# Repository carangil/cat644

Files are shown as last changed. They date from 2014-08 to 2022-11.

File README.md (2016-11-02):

cat644
======

Cat-644 is a microcomputer based around the Atmega644 microcontroller.  This repository will hold both hardware designs and software source code.

dirs:

schematics/  	hardware information
cat1/  			OLD hardware test routines.  Will be deleted when CAT-OS is finished
cat-os/			'scratchpad' OS.  Being built out of code in the cat1 directory

LICENSE

All code is under GPL v2.  See LICENSE file for details.

All code written by Mark Sherman, with a few exceptions:

'wait until' function taken from arduino-tvout: http://code.google.com/p/arduino-tvout/  (License: MIT License)

The 'general idea' of VGA generation from an AVR was taken from these resources:
http://www.lucidscience.com/pro-vga%20video%20generator-1.aspx
http://quinndunki.com/blondihacks/?p=955
http://avga.prometheus4.com/

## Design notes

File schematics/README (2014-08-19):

.sch and .sym files are in gEDA format.
The 'schematics' folder must be added to your gEDA configuration as a library.

'fullcomputer.sch' contains the entire design, and is provided in both eps and png formats.

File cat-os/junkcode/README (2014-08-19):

Code here is not integrated into the cat-os project currently, but is kept here as a backup.  Eventually the junkcode folder will be empty, and the project will be done!

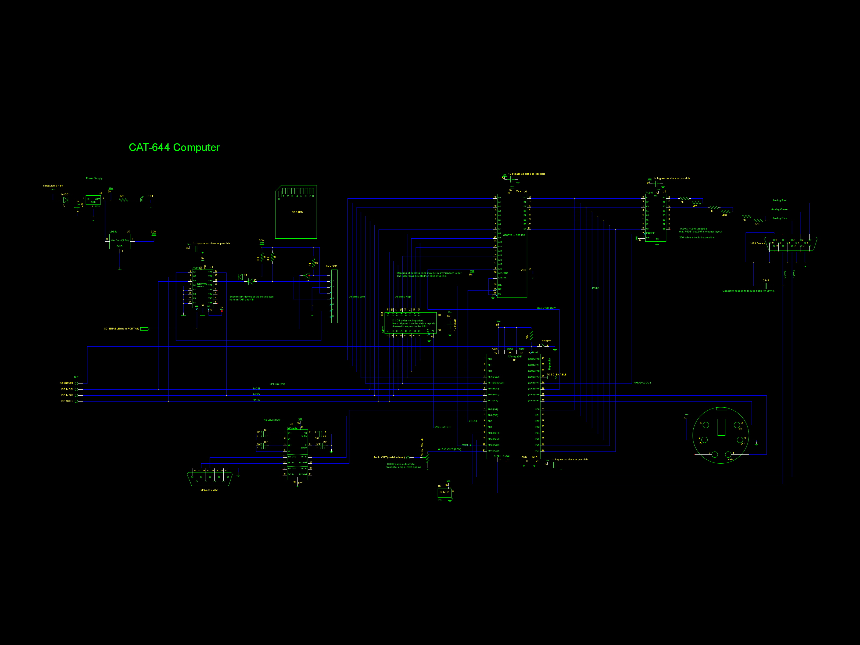
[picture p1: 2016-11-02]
schematics/fullcomputer.png

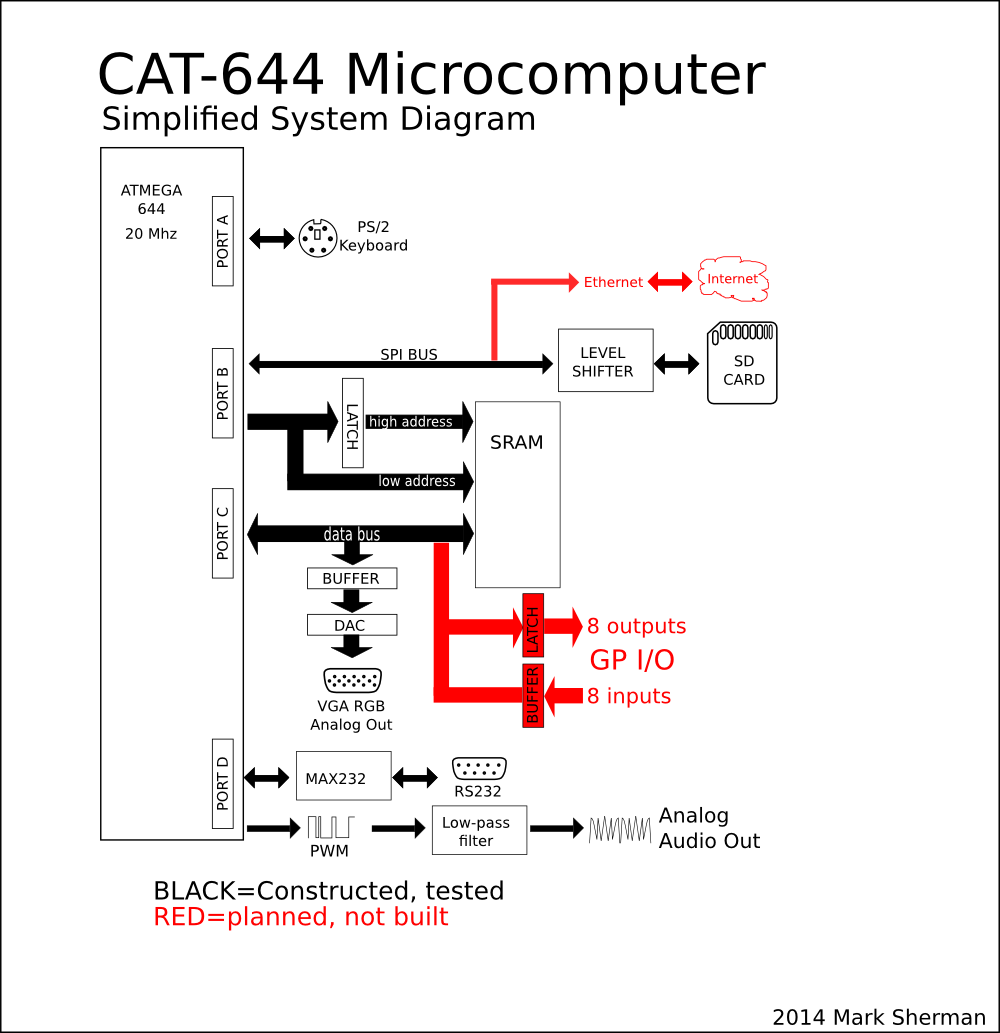
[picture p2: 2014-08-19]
schematics/sysdiag.png

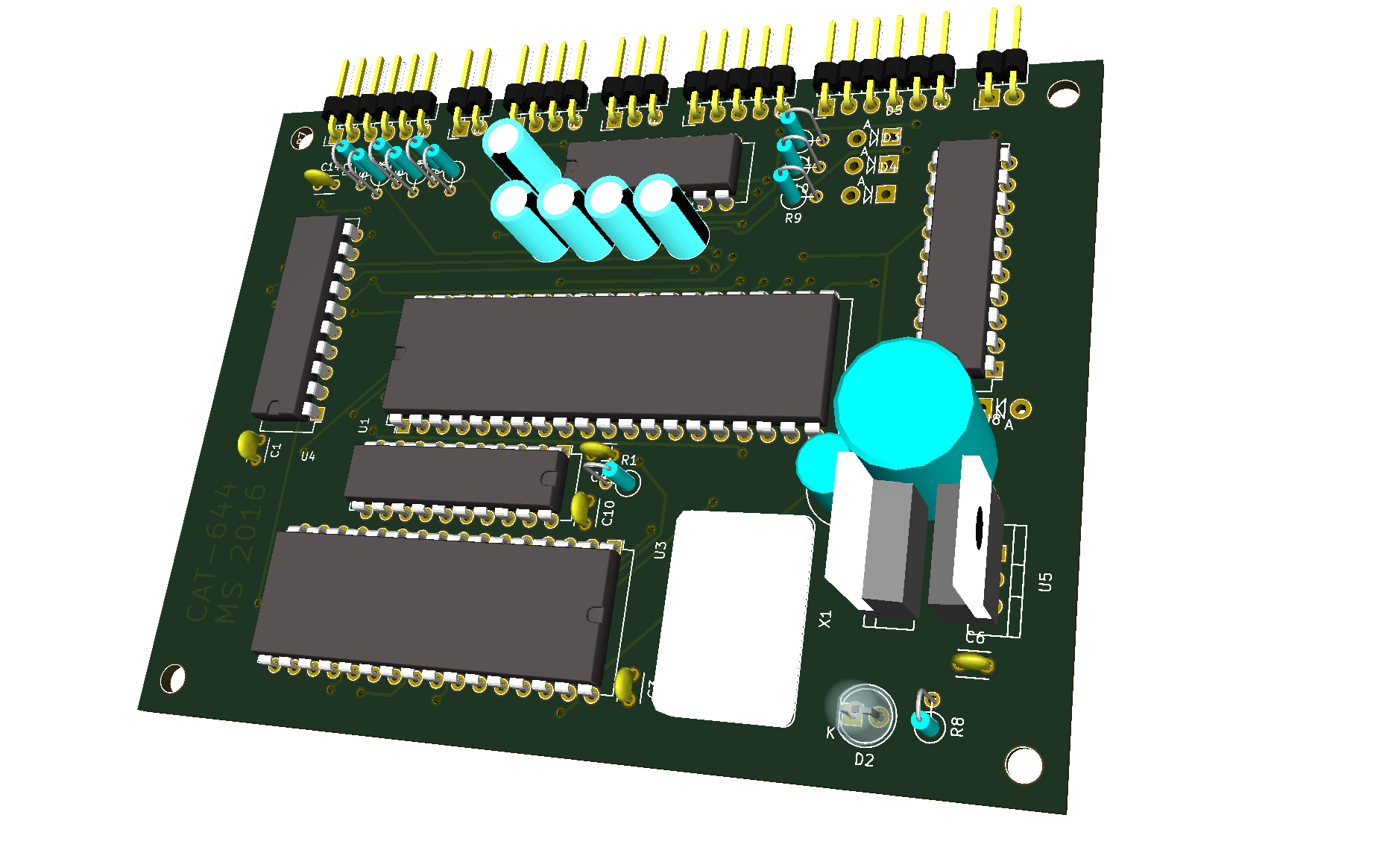
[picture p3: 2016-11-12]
kicad/cat644.png

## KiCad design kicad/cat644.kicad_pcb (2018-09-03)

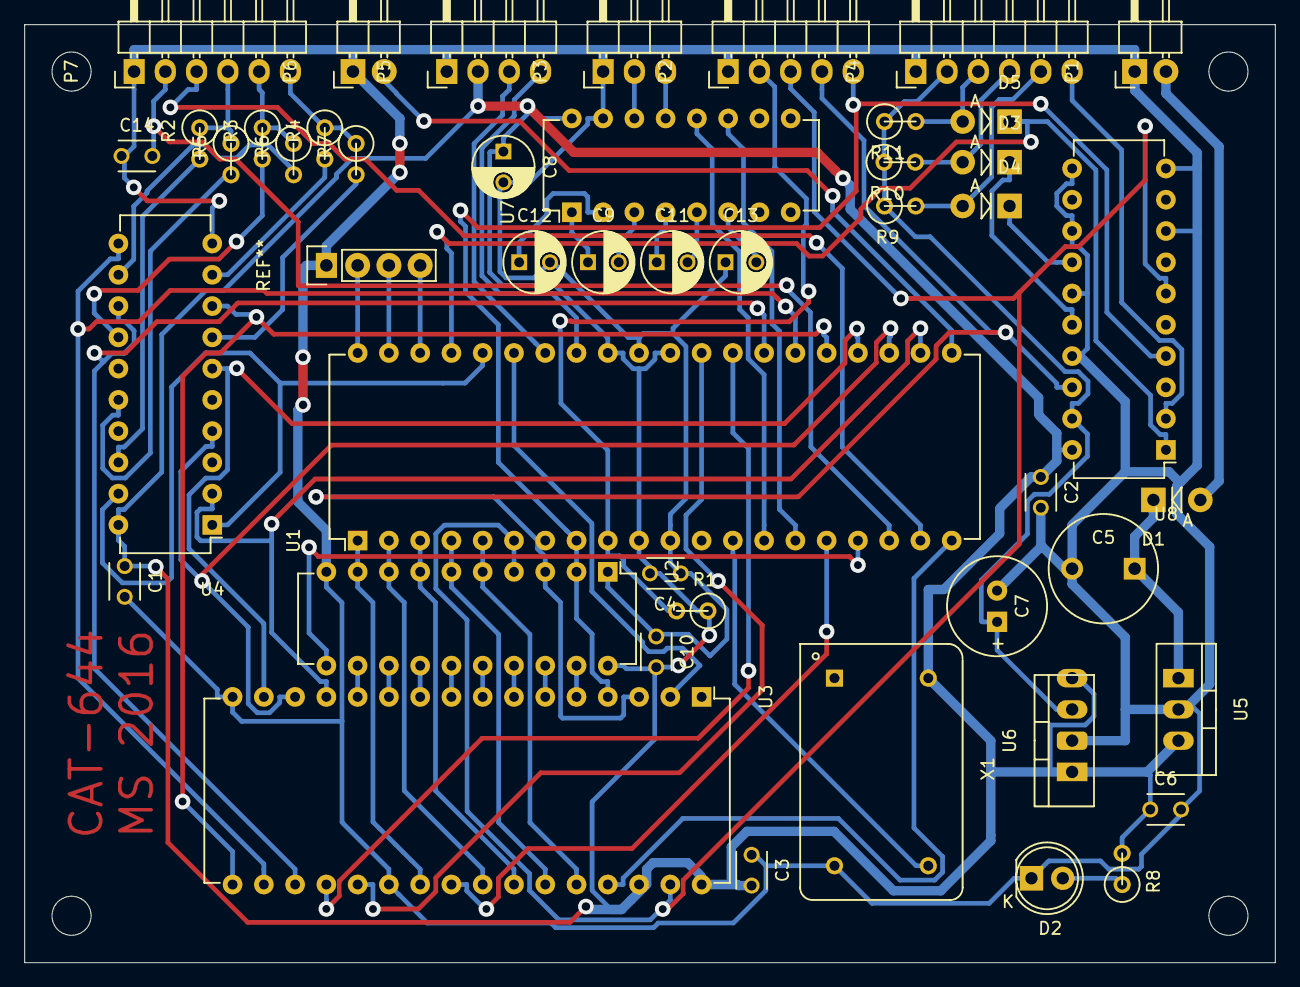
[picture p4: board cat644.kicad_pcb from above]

Board: 2 copper layers, 101.6 x 76.2 mm, 50 parts (0 on the bottom side), 68 nets.

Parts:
C1, C2, C3, C4, C10: 0.1uF; C_Disc_D3_P2.5
C5: 470uF; C2V8
C6: 0.1 uF; C_Disc_D3_P2.5
C7: 2.2 uF; C1V8
C8: 10uF; C_Radial_D5_L11_P2.5
C9, C11, C12, C13: 1uF; C_Radial_D5_L11_P2.5
C14: 0.01uF; C_Disc_D3_P2.5
D1: 1N4001; Diode_DO-41_SOD81_Vertical_AnodeUp
D2: LED; LED-5MM
D3, D4, D5: D; Diode_DO-41_SOD81_Vertical_AnodeUp
P1: PWR; Pin_Header_Angled_1x02
P2: ISP; Pin_Header_Angled_1x05
P3: SER; Pin_Header_Angled_1x03
P4: SD; Pin_Header_Angled_1x06
P5: PS2; Pin_Header_Angled_1x04
P6: AUD; Pin_Header_Angled_1x02
P7: VGA; Pin_Header_Angled_1x06
R1: 10k; R1
R2, R3, R4: 1k; R1
R5, R6, R7, R8: 470; R1
R9, R10, R11: 5k; R1
U1: ATMEGA644-P; DIP-40_W15.24mm
U2: 74LS573; DIP-20_W7.62mm
U3: 628128; DIP-32_W15.24mm
U4, U8: 74LS244; DIP-20_W7.62mm
U5: 7805; TO-220_Neutral123_Vertical
U6: LF33; TO-220_Neutral123_Vertical
U7: MAX232; DIP-16_W7.62mm
X1: OSC 20MHz; KXO-200
mh1, mh2, mh3, mh4: MountingHole_3.5mm

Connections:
/av/AUDIO_OUT: P6.2, U1.21
/av/HSYNC: P7.3, U1.19
/av/VGA_BLUE: P7.6, R4.1, R7.1
/av/VGA_GREEN: P7.5, R3.1, R6.1
/av/VGA_RED: P7.4, R2.1, R5.1
/av/VSYNC: C14.2, P7.2, U1.18
/serial/MISO: P2.4, U1.7, U2.3, U3.3, U8.18
/serial/MOSI: P2.3, U1.6, U2.4, U3.31, U8.6
/serial/PS2_DATA: P5.3, U1.34
/serial/PS2_DK: P5.4, U1.33
/serial/RESET: P2.2, R1.2, U1.9
/serial/RX1_OUT: U1.14, U7.12
/serial/SCLK: P2.5, U1.8, U2.2, U3.4, U8.4
/serial/SD_ENABLE: D5.1, U1.37, U8.1
/serial/TX1_IN: U1.15, U7.11
GND: C1.2, C2.2, C3.1, C4.1, C5.2, C6.2, C7.2, C8.2, C10.1, C12.2, C13.1, C14.1, D2.1, P1.1, P2.1, P3.1, P4.1, P5.1, P6.1, P7.1, U1.11, U1.31, U2.1, U2.10, U3.16, U3.22, U4.10, U5.2, U6.2, U7.15, U8.8, U8.10, U8.11, U8.13, U8.15, U8.17, X1.7
unnamed: C5.1, D1.1, U5.1
unnamed: C9.1, U7.1
unnamed: C9.2, U7.3
unnamed: C11.1, U7.4
unnamed: C11.2, U7.5
unnamed: C12.1, U7.2
unnamed: C13.2, U7.6
unnamed: D1.2, P1.2
unnamed: D2.2, R8.1
unnamed: D3.1, U8.16
unnamed: D3.2, P4.4, R10.2
unnamed: D4.1, U8.14
unnamed: D4.2, P4.5, R9.2
unnamed: D5.2, P4.3, R11.2
unnamed: P3.2, U7.14
unnamed: P3.3, U7.13
unnamed: P4.6, U8.2
unnamed: R2.2, U4.18
unnamed: R3.2, U4.14
unnamed: R4.2, U4.9
unnamed: R5.2, U4.16
unnamed: R6.2, U4.12
unnamed: R7.2, U4.7
unnamed: U1.1, U2.9, U3.23
unnamed: U1.2, U2.8, U3.25
unnamed: U1.3, U2.7, U3.26
unnamed: U1.4, U2.6, U3.27
unnamed: U1.5, U2.5, U3.28
unnamed: U1.13, X1.8
unnamed: U1.16, U3.24
unnamed: U1.17, U2.11
unnamed: U1.20, U3.29
unnamed: U1.22, U3.13, U4.2
unnamed: U1.23, U3.14, U4.4
unnamed: U1.24, U3.15, U4.6
unnamed: U1.25, U3.17, U4.8
unnamed: U1.26, U3.18, U4.11
unnamed: U1.27, U3.19, U4.13
unnamed: U1.28, U3.20
unnamed: U1.29, U3.21
unnamed: U1.35, U3.2
unnamed: U1.36, U4.1, U4.19
unnamed: U2.12, U3.12
unnamed: U2.13, U3.11
unnamed: U2.14, U3.10
unnamed: U2.15, U3.9
unnamed: U2.16, U3.8
unnamed: U2.17, U3.7
unnamed: U2.18, U3.6
unnamed: U2.19, U3.5
VCC: C1.1, C2.1, C3.2, C4.2, C6.1, C8.1, C10.2, P5.2, R1.1, R8.2, U1.10, U1.30, U1.32, U2.20, U3.30, U3.32, U4.20, U5.3, U6.1, U6.4, U7.16, U8.20, X1.14
VDD: C7.1, P4.2, R9.1, R10.1, R11.1, U6.3, U8.19

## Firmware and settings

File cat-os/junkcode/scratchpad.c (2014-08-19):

/*
 * cat1.c
 *
 * Created: 6/1/2013 5:41:14 AM
 *  Author: Mark Sherman
 */ 

#define F_CPU 20000000

#include <avr/io.h>
#include <avr/interrupt.h>
#include <util/delay.h>
#include <stdio.h>
#include <string.h>

#include "keycodes.h"


//Serial port

void comm_init(uint16_t baud)
{
	//baud rate calculation (based on code from http://www.embedds.com/programming-avr-usart-with-avr-gcc-part-1/)
	UBRR0 = (uint16_t)(((F_CPU / (baud * 16UL))) - 1) ;
	
	// Set frame format to 8 data bits
	UCSR0C = _BV(UCSZ01) | _BV(UCSZ00);
		 
	//start
	UCSR0B|= _BV(RXEN0) | _BV(TXEN0);
}


void comm_init_115200()
{
	//baud rate calculation (based on code from http://www.embedds.com/programming-avr-usart-with-avr-gcc-part-1/)
	UBRR0 = 0xA ;  //assume 20 mhz
	
	// Set frame format to 8 data bits
	UCSR0C = _BV(UCSZ01) | _BV(UCSZ00);
	
	//start
	UCSR0B|= _BV(RXEN0) | _BV(TXEN0);
}

#define COMM_SEND_READY  ( UCSR0A& _BV(UDRE0) )

void comm_putc(unsigned char c)
{
	//wait for it
	while(!COMM_SEND_READY);
	
	//write to output register
	UDR0 = c;
}


#define COMM_READ_READY ( UCSR0A & _BV(RXC0) )

unsigned char comm_getc()
{
	
	while(!COMM_READ_READY);
	
	return UDR0;
}

//takes a reader/writer function function
//writer function null for no echo

void readline(unsigned char (*reader)() , void (*writer)(unsigned char), char* str, uint8_t siz)
{
	uint8_t c=0;
	uint16_t cnt = 0;
		
	
	while ((cnt < siz))
	{
		c = reader();
		
		
		if(writer)
			writer(c); //echo it
			
		if (c=='\n')
			break; //done
		
		*(str++) = c;	
		cnt++;
	}
	
	*str = 0; //null terminate
}

void prints(void (*writer)(unsigned char), char* str)
{
	while(*str)
	{
		writer(*str);
		str++;
	}
	
}



//external ram

//ram control (write/read)  signals
#define RAMCTRL_PORT  PORTD
#define RAMCTRL_DDR   DDRD
#if 0
#define RAMCTRL_DDR_MASK 0b11001000  /*three outputs*/

#define RAMCTRL_MASK     0b00110111   /*all bits not used for ram control*/
#define RAMCTRL_WE_MASK  0b01000000    
#define RAMCTRL_OE_MASK  0b10000000
#define RAMCTRL_PL_MASK  0b00001000
#endif

#define RAMCTRL_DDR_MASK 0b01001100  /*three outputs*/
#define RAMCTRL_MASK     0b10110010  /*all bits not used for ram control*/
#define RAMCTRL_WE_MASK  0b01000000  /*d.6*/  
#define RAMCTRL_OE_MASK  0b00000100  /*d.2*/
#define RAMCTRL_PL_MASK  0b00001000  /*d.3*/

//address bus signals
#define RAMADDR_PORT PORTB
#define RAMADDR_DDR  DDRB

#define RAMEX_PORT				PORTA
#define RAMEX_DDR				DDRA
#define RAMEX_DDR_MASK			0b00100000  /* 1 output */
#define RAMEX_A16_HIGH_MASK		0b00100000  /* A16 bit */
#define RAMEX_A16_LOW_MASK		0b11011111  /* A16 bit */

//data bus signals
#define RAMDATA_PORT PORTC
#define RAMDATA_DDR  DDRC
#define RAMDATA_PIN  PINC

//select different pages of 256 bytes each
// (go through funcion so we can switch to using multiplexing high address later if we want



void initram()
{
	//no write, no read
	RAMCTRL_PORT = (RAMCTRL_PORT&RAMCTRL_MASK) | RAMCTRL_WE_MASK | RAMCTRL_OE_MASK;
		
	//set data bus direction
	RAMDATA_DDR = 0x0;  //all input
	RAMDATA_PORT = 0x0; //no pullup
	
	//write enable up, output enable down (RAM output is enabled)
	
	RAMCTRL_DDR =  RAMCTRL_DDR_MASK;
	
	//set to read mode  (write enable high, output enable low)
	RAMCTRL_PORT = (RAMCTRL_PORT&RAMCTRL_MASK) | RAMCTRL_WE_MASK ;

	//set address port direction
	RAMADDR_DDR = 0xFF;  //all output
}


//set address on port (low part of address)

#define SETADDRESSLOW(addr)  RAMADDR_PORT = addr;

//select which 'page'
//the high part of the address is set and strobed
//after this the low part of the address will have to be set again later

volatile unsigned char lastpage=0;




#define SELECT_RAM_PAGE(zzzp) \
  lastpage=(zzzp); \
  SETADDRESSLOW((zzzp)); \
  RAMCTRL_PORT |= RAMCTRL_PL_MASK;    /*latch output*/ \
  asm volatile("nop"); \
  asm volatile("nop");  \
   asm volatile("nop");  \
  RAMCTRL_PORT = RAMCTRL_PORT & (~RAMCTRL_PL_MASK); 
 

  
 //this version doesn't save the selected address (for use in interrupts)
 
#define SLOW_SELECT_RAM_PAGE_NOSAVE_MACRO(zzzp) \
  SETADDRESSLOW((zzzp)); \
  RAMCTRL_PORT |= RAMCTRL_PL_MASK;    /*latch output*/ \
  asm volatile("nop"); \
  asm volatile("nop");  \
   asm volatile("nop");  \
  RAMCTRL_PORT = RAMCTRL_PORT & (~RAMCTRL_PL_MASK); 

#define SELECT_RAM_PAGE_NOSAVE_MACRO(zzzp) \
SETADDRESSLOW((zzzp)); \
RAMCTRL_PORT |= RAMCTRL_PL_MASK;    /*latch output*/ \
RAMCTRL_PORT = RAMCTRL_PORT & (~RAMCTRL_PL_MASK);


//write one byte
//strobes high part of address
//also returns ram back to 'reading' mode

void slowwrite(unsigned int address, unsigned char value)
{
	//return;
	
	
		
	SELECT_RAM_PAGE(address >> 8);
	//select_ram_page(address>>8);
	
	SETADDRESSLOW(address);
	//no output
	//settle address
	asm volatile("nop");   //delay 1 cycle (50 ns)
	asm volatile("nop");   //delay 1 cycle (50 ns)
	
	RAMCTRL_PORT   |= RAMCTRL_OE_MASK; //disable OE
	
	//write enable

	//write!
	
	//cli();
	
	RAMCTRL_PORT = RAMCTRL_PORT & (~RAMCTRL_WE_MASK);   //write enable down
	
	RAMDATA_PORT = value;  //output the value
	RAMDATA_DDR = 0xff; //all output
	
	asm volatile("nop");   //delay 1 cycle (50 ns)
	asm volatile("nop");   //delay 1 cycle (50 ns)
	asm volatile("nop");   //delay 1 cycle (50 ns)
	
	//no input/output
	RAMCTRL_PORT   |= RAMCTRL_WE_MASK;  //write enable up (stop writing)
		
	//sei();
	
	RAMDATA_DDR = 0x00;	 //all input
	RAMDATA_PORT = 0;    //no pullup
	
	//back to default reading mode
	RAMCTRL_PORT = RAMCTRL_PORT & (~RAMCTRL_OE_MASK);
	
	
}


//begin a series of fast writes
//when writing fast, data bus is left in output state between writes
//OE is also kept high
//fast writes also only change the low address (must call set select ram page to move hi part)

#define START_FAST_WRITE  \
	 RAMCTRL_PORT = (RAMCTRL_PORT&RAMCTRL_MASK) | RAMCTRL_WE_MASK | RAMCTRL_OE_MASK ; \
	 RAMDATA_DDR = 0xff;
	 
//fast write into the currently enabled page

#define FAST_WRITE(zlowaddr,zbyte) \
	RAMADDR_PORT = (zlowaddr); \
	RAMDATA_PORT = (zbyte); \
	RAMCTRL_PORT = RAMCTRL_PORT & (~RAMCTRL_WE_MASK); \
/*	asm volatile("nop"); */  \
/*  asm volatile("nop"); */  \
/*  asm volatile("nop"); */  \
	RAMCTRL_PORT |= RAMCTRL_WE_MASK;  //we up
	
//return ram to reading move
#define END_FAST_WRITE  \
	RAMCTRL_PORT = (RAMCTRL_PORT&RAMCTRL_MASK) | RAMCTRL_WE_MASK  ;


//strobes hi part of address
unsigned char slowread(unsigned int address)
{
	SELECT_RAM_PAGE(address >> 8);
	
	SETADDRESSLOW(address & 0xFF);
	
	asm volatile("nop");   //delay 1 cycle (50 ns)
	asm volatile("nop");   //delay 1 cycle (50 ns)
	asm volatile("nop");   //delay 1 cycle (50 ns)

	return RAMDATA_PIN;
}

//keyboard input (ps/2)

#define KEY_PORT  PORTA
#define KEY_DDR   DDRA
#define KEY_PIN   PINA
#define KEY_MASK  0b00111111
#define KEY_CLK   0b10000000
#define KEY_DATA  0b01000000


//#define KEY_INTERRUPT 


//if enable interript is not set, we need to poll
void init_key()
{
	//KEY_PORT &= KEY_MASK; //no pullups
	
	KEY_DDR &= KEY_MASK;  //keyboard are inputs
	KEY_PORT |= KEY_CLK |KEY_DATA ; //pullup
	
	
	#if 0
		//debug only: no pullup
		KEY_PORT=0;
	#endif
		
	#ifdef KEY_INTERRUPT
	
	PCICR |= (1 << PCIE0);  //enable pin change interrupt
	PCMSK0 |= (1<<PCINT7);	 //enable PCINT7
	
	#endif
}

#define KEYB_SIZE 10
volatile char keyb_readpos=0;  //written by reader
volatile char keyb_writepos=0; //written by driver
volatile char keyb[KEYB_SIZE];
volatile char keybits=0;
volatile char keybitcnt=0;

#define SETA16LOW  RAMEX_PORT &= RAMEX_A16_LOW_MASK
#define SETA16HIGH RAMEX_PORT |= RAMEX_A16_HIGH_MASK 

#define A16(n) (n ?  (SETA16HIGH) : (SETA16LOW) )

void ramex_init()
{
	RAMEX_DDR |= RAMEX_DDR_MASK;  //enable one output
	SETA16LOW;
	
	
}



volatile char debugkeys[11];
volatile char debugkeypos=0;


unsigned char nextkey(){
	unsigned char x;
	
	if (keyb_writepos == keyb_readpos)
		return 0;
		
	x = keyb[keyb_readpos++];
	if (keyb_readpos >= KEYB_SIZE)
		keyb_readpos = 0;
	
	return x;
}


volatile unsigned char keybh=0;
ISR (PCINT0_vect)
{
	keybh=1;
	
	if (!(KEY_PIN & KEY_CLK))
	{
		char inbit = (KEY_PIN&KEY_DATA)<<1;
		
	
		debugkeys[debugkeypos]=inbit;
		debugkeypos++;
		debugkeypos = debugkeypos % 11;
		
		
		//this was a falling edge
		
		if (keybitcnt==0)
		{
			if (inbit==0)
				keybitcnt++;
		}
		else if (keybitcnt<9)
		{
			keybits = keybits>>1;
			keybits |= inbit;
			keybitcnt++;
		}
		else if (keybitcnt==9)
			keybitcnt++;
		else { //cnt is 10 (11th bit of frame)
			if (inbit==128)  
			{
				keyb[keyb_writepos] = keybits;  //write in buffer
				if (keyb_writepos==(KEYB_SIZE-1))
					keyb_writepos=0;
				else
					keyb_writepos++;
				
			}
			
			keybitcnt=0;
		}
		
	}
	
}

//poll keyboard with no interrupts
char oldclock = 1;

void inline  keypoll(unsigned char portin) {
	
		char inbit = (portin & KEY_DATA)<<1;
		
		/*
		debugkeys[debugkeypos]=inbit;
		debugkeypos++;
		debugkeypos = debugkeypos % 11;
		*/
		
		
		//this was a falling edge
		
		if (keybitcnt==0)
		{
			if (inbit==0)
			keybitcnt++;
		}
		else if (keybitcnt<9)
		{
			keybits = keybits>>1;
			keybits |= inbit;
			keybitcnt++;
		}
		else if (keybitcnt==9)
		keybitcnt++;
		else { //cnt is 10 (11th bit of frame)
			if (inbit==128)
			{
				keyb[keyb_writepos] = keybits;  //write in buffer
				if (keyb_writepos==(KEYB_SIZE-1))
				keyb_writepos=0;
				else
				keyb_writepos++;	
			}	
			keybitcnt=0;
		}	
	
}


//try some vga

#define VGA_DDR			DDRD
#define VGA_DDR_MASK	0b00110100 /*three outputs*/
#define VGA_PORT		PORTD

#define VGA_MASK        0b11001011  /*all other bits*/
#define VGA_HSYNC_MASK  0b00100000  /* d.5*/
#define VGA_VSYNC_MASK  0b00010000  /*d.4*/

/* VGA DAC might be on different port */
//#define VGA_DAC_PORT	PORTD
//#define VGA_DAC_DDR		DDRD
//#define VGA_DAC_MASK    0b00000100  /*d.2*/

#define VGA_DAC_PORT	PORTA
#define VGA_DAC_DDR		DDRA
#define VGA_DAC_MASK    0b00010000  /*a.4*/


int mwscnt=0;
//which page to draw
volatile char vga_a16=0;

#define VGA_SCREEN(n) vga_a16= (n) << 5 ;  //if ramex a16 is a.5


volatile unsigned char fpend=0;
volatile unsigned int syncend=0;
volatile unsigned int bpend=0;
volatile unsigned int vgalen_full=0;
volatile unsigned int vgalen_half=0;

static char vsyncstate=VGA_VSYNC_MASK; 

//char bob=0;
//volatile unsigned char pageselok=1;

volatile unsigned char lscroll=0;

//copied from arduino tv-out
static inline void wait_until(unsigned char time) {
	
	__asm__ __volatile__ (
	"sub	%[time], %[tcnt1l]\n\t"
	"subi	%[time], 10\n"
	"100:\n\t"
	"subi	%[time], 3\n\t"
	"brcc	100b\n\t"
	"subi	%[time], 0-3\n\t"
	"breq	101f\n\t"
	"dec	%[time]\n\t"
	"breq	102f\n\t"
	"rjmp	102f\n"
	"101:\n\t"
	"nop\n"
	"102:\n"
	:
	: [time] "a" (time),
	[tcnt1l] "a" (TCNT1L)
	);
}


#if 1

static unsigned char hires=0;

#define PX1(cnt)  __asm__ __volatile__ (\
"subi %[j], -1 \n" \
"out 0x5, %[j] \n" \
: : [j] "a" (cnt));

#define PX9(cnt)  __asm__ __volatile__ (\
"subi %[j], -9\n" \
"out 0x5, %[j] \n" \
: : [j] "a" (cnt));

unsigned char kp=0;

unsigned char active_video=1;
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
int main(void)
{

	char str[200];
	int i,j;
	char wcount=0;
	
	/* Disable JTAG port */
	MCUCR |= _BV(JTD);
	MCUCR |= _BV(JTD);
		
	//Initialize USART0
	//comm_init(19200);
	comm_init(56000);
	//comm_init_115200();
	prints (comm_putc,"start\n");
	
	spi_init();
	sdcard_init();


	if (sdcard_read_block(0, buffer)) {
		
		for (i=0;i<512;i++) {
			sprintf(str, "%x ", buffer[i] );
			prints(comm_putc, str);
		}
		
	}else
		prints (comm_putc,"fail\n");
	

	init_key();  //initialize keyboard, but with no interrupts

	sei();
	
	#if 0
	//cause pin change interrupt
	//only use in debugger!
//	DDRA=0xff;
	//PORTA=0;
//	PORTA=0xff;
	#endif
	
//keyloop
#if 0
	while(1){
		char i;
		unsigned char x;

		
		sprintf( str, "keybh %d : " , keybh   );
		prints (comm_putc,str) ;
				
		keybh=0;
		
			for (i= 0; i<11;i++)
			{
				sprintf( str, "%d.", debugkeys[ (debugkeypos + i) % 11] );
				prints (comm_putc,str);
			}
			prints(comm_putc,"\r\n");
		_delay_ms(100);
		
		while (1)
		{
				x=nextkeychar();
				if (!x)
					continue;
				//sprintf( str, "%x[%c]", x, x);
				
			//	prints(comm_putc, str);
				//_delay_ms(100);
		}
		
//		while ((x = nextkey()))
	//	{
			
		//	sprintf( str, "keyboard code %x\r\n", x);
			//prints (comm_putc,str);
			
	//	}
		
		
	}
#endif

	initram();
	ramex_init();
	
	vga_init();
	prints (comm_putc,"Testing comm hello ") ;
		
	
	
	VGA_SCREEN(0);
	A16(0);
	
	
	while(1)
	{
		unsigned int i;
		unsigned int j;
		prints(comm_putc, "This version is" __DATE__  " " __TIME__ "\n");
		
		
		prints(comm_putc,"writing color pattern \r\n");
		for (j=0;j<240;j++)
		{
			for (i=0;i<256;i++)
			{
				char c;
				c= i>>2;
				
				if (j<32)
				c&=0b000011;
				else if (j<64)
				c&=0b001100;
				else if (j<128)
				c&=0b110000	;
				
				slowwrite((j<<8) | i, c ) ;
			}
		}
		
		HOME;
		prints(screen_write_one, "Hello type something");
		while(1) {
			
		prints(screen_write_one, "a");	
		}
		while(1) {
			
			
			
			prints(screen_write_one, ">");
			readline(key_getc, screen_write_one, str, sizeof(str)-1);
			
			if (!strncmp(str, "color ", 6))
			j = atoi(str+6);
			if (j)
				color=j;
				
			prints(screen_write_one,"\r\nYou said ");
			prints(screen_write_one,str);
			prints(screen_write_one,"\r\n");
			
			
			if (!strcmp(str, "sound"))
			{
				
				
				//black
				for (j=0;j<240;j++)
				{
					for (i=0;i<256;i++)
					{
						slowwrite((j<<8) | i,  0  ) ;
					}
				}
				
				HOME;
				prints(screen_write_one, "Sound and Video together");
				
				snd_init();
							
				
			}
			
			
			if (!strcmp(str, "cls"))
			{
				for (j=0;j<240;j++)
				{
					for (i=0;i<256;i++)
					{
						
						
						slowwrite((j<<8) | i, 0 ) ;
					}
				}
				
				HOME;
				
			}
			
			if (!strcmp(str, "test"))
			{
				prints(screen_write_one,"\r\nContinuing test program\r\n");
				break;
			}
			
			if (!strcmp(str, "read"))
			{
				
				while (1)
				{
					
				
					while ( PIND & VGA_VSYNC_MASK); //wait until vsync goes low
					active_video=0;
					
					if (sdcard_read_block(0, buffer)) {
						active_video=1;
					/*	for (i=0;i<512;i++) {
							sprintf(str, "%x ", buffer[i] );
							prints(comm_putc, str);
						}
						*/
					
					}else
					prints (comm_putc,"fail\n");
					active_video=1;
				
				}
				
			}
			
		}
		
		
		
		prints(comm_putc,"Hello type something \r\n");
		//lscroll ++;
		
	/*	for (i= 0; i<11;i++)
		{
			sprintf( str, "%d.", debugkeys[ (debugkeypos + i) % 11] );
			prints (str);
		}
		prints("\r\n");
		*/
		
		#if 0
		{
			unsigned char x;
			
			while ((x = nextkey()))	
			{
		
				sprintf( str, "keyboard code %x\r\n", x);
				prints (comm_putc,str);
				
			}
			
		}
		#endif
		
		if ( COMM_READ_READY)
		{
			prints(comm_putc, ">");
			readline(comm_getc, comm_putc, str, sizeof(str)-1);
		
			prints(comm_putc,"\r\nYou said ");
			prints(comm_putc,str);
			prints(comm_putc,"\r\n");
		}
		
		wcount++;
		
		prints(comm_putc,"Writing test pattern 1!\r\n");
		
		_delay_ms(100);
		
		prints(comm_putc, "Testing RAM data lines\n");
		for(i=0;i<255;i++)
		{
			slowwrite(	i, i);			
		}
		for (i=0;i<255;i++)
		{
			j = slowread(i);
			sprintf(str, "%x ", j);
			prints(comm_putc,str);
			
			if	(i!=j) 
				prints(comm_putc, "<-err\n");
			
		}
		
	//	pageselok=0;
		
		for (j=0;j<240;j++)
		{
			for (i=0;i<256;i++)
			{			
				slowwrite((j<<8) | i, 0xff ) ;
			}
		}
		
		prints(comm_putc,"writing color pattern \r\n");
		for (j=0;j<240;j++)
		{
			for (i=0;i<256;i++)
			{
				char c;
				c= i>>2;
				
				if (j<32)
					c&=0b000011;
				else if (j<64)
					c&=0b001100;
				else if (j<128)
					c&=0b110000	;
				
				slowwrite((j<<8) | i, c ) ;
			}
		}
		
		
		
		//pageselok=1;
		_delay_ms(1000);
	//	pageselok=0;

		prints(comm_putc,"writing test pattern 2\r\n");	
		for (j=0;j<240;j++)
		{
			for (i=0;i<256;i++)
			{
				slowwrite((j<<8) | i, 0x01 ) ;
			}
		}
		
		prints(comm_putc,"writing test pattern 3\r\n");
	//pageselok=1;
	_delay_ms(100);
	//pageselok=0;

		
		//green should be faster than all the others
		START_FAST_WRITE;
		for (j=0;j<240;j++)
		{
			//cli();
			SELECT_RAM_PAGE(j);
			//sei();
			for (i=0;i<256;i++)
			{
				FAST_WRITE(i,0x02);
			}
		}
		END_FAST_WRITE;
		
		//pageselok=1;
		_delay_ms(100);
		//pageselok=0;

	
		prints(comm_putc,"writing test pattern 4 perfect?\r\n");
		
		for (j=0;j<240;j++)
		{
			for (i=0;i<256;i++)
			{
				slowwrite((j<<8) | i, 0x04 ) ;
			}
		}
		
	//pageselok=1;
	_delay_ms(100);
	//pageselok=0;

		

		prints(comm_putc,"writing test pattern 5\r\n");
			
		for (j=0;j<240;j++)
		{
			for (i=0;i<256;i++)
			{
				slowwrite((j<<8) | i, (j>>2) ^  (i>>2) ) ;
			}
		}
	
	

	//pageselok=1;
	_delay_ms(100);
	//pageselok=0;

	
		//draw cat
		for (j=0;j<240;j++)
		{
			for (i=0;i<256;i++)
			{
				unsigned char catx = (i ) & 0xf;
				unsigned char caty = (j ) & 0xf;
				slowwrite((j<<8) | i, cat[(caty<<4) | catx] ) ;
			}
		}
		
		//draw cat large, multicolor
		START_FAST_WRITE;
		for (j=0;j<240;j++)
		{
			unsigned char caty = (j/4 ) & 0xf;
			SELECT_RAM_PAGE(j);
			for (i=0;i<256;i++)
			{
				unsigned char catx = (i/4 ) & 0xf;
				
				unsigned char color = (((i/2)+(j/2))%7)+1;
				
				//slowwrite((j<<8) | i,  (cat[(caty<<4) | catx])  *  color) ;
				FAST_WRITE(i,(cat[(caty<<4) | catx])  *  color );
			}
		}
		END_FAST_WRITE;
		
		
		//black
		for (j=0;j<240;j++)
		{
			for (i=0;i<256;i++)
			{
				slowwrite((j<<8) | i,  0  ) ;
			}
		}
			
			hires=1;
			
			//draw a character
			HOME;
			
			for (i=0;i<16;i++)
			{
				sprintf(str, "Hello hires %d!\n" , i);
				
				screen_writehi(str);
				
			}
			
			A16(1);
			//black
			for (j=0;j<240;j++)
			{
				for (i=0;i<256;i++)
				{
					slowwrite((j<<8) | i,  0  ) ;
				}
			}
			HOME;
			
			for (i=0;i<16;i++)
			{
				sprintf(str, "Hello hires side 2 %d  %c %c !\n" , i,1,1);
				
				screen_writehi(str);
				
			}
			A16(0);
			
			for (j=0;j<5;j++)
			{
				
				
				//VGA_SCREEN(1);
				A16(1);
				_delay_ms(300);
			
				//VGA_SCREEN(0);
				A16(0);
				_delay_ms(300);
			}
			hires=0; //back to lowres
			
			
			#if 0
			//clear
			for (j=0;j<240;j++)
			{
				for (i=0;i<256;i++)
				{
					slowwrite((j<<8) | i,  0  ) ;
				}
			}
			
			for (j=0;j<10;j++)
			{
				
			
				for (i=0;i<240; i+=1 )
				{
				
				
					drawchar(i, i, '*', 2, 0);
					drawchar(i, 240-i, '-', 7, 0);
					//_delay_ms(10);
				
					drawchar(i, i, ' ', 2, 0);
					drawchar(i, 240-i, ' ', 3, 0);
				
				}
			
			}
			_delay_ms(1000);
			#endif
			//pageselok=1;
			
		sei();	
	}
}

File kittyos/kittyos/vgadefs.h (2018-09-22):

/*
 * vgadefs.h
 *
 * Created: 9/4/2018 8:41:06 PM
 *  Author: mark
 */ 


#ifndef VGADEFS_H_
#define VGADEFS_H_

//choose VGA driver algorithm:
//#define VGA_NOTCHY  //will blank out parts of a scanline to handle a key
#define VGA_SPAGHETTI  //handles the keyboard inside of vertical blanking by withhold cycles from the user program.  Longer than usual interrupts.



#define VGA_DDR			DDRD
#define VGA_DDR_MASK	0b00110100 /*three outputs*/
#define VGA_PORT		PORTD

#define VGA_MASK        0b11001011  /*all other bits*/
#define VGA_VSYNC_MASK  0b00100000  /* d.5*/
#define VGA_HSYNC_MASK  0b00010000  /*d.4*/

#define VGA_DAC_PORT	PORTA
#define VGA_DAC_DDR		DDRA
#define VGA_DAC_MASK    0b00010000  /*a.4*/
#define VGA_DAC_BITNUM	4

//old
#define VGA_HSYNC_HIGH			76
#define VGA_HSYNC_LOW		(636-20)


#define BACKPORCH	36
#define HSYNC		76
#define HSYNCGOESHIGH	54
#define HSYNCGOESLOW	636 - HSYNC + HSYNCGOESHIGH

//0 AKA 636 is when interrupt fires 
//  HSYNCGOES HIGH is when HSYNC IS DONE, SO   HSYNCGOESHIGH - 76 + 636 is when HSYNC GOES LOW





#endif /* VGADEFS_H_ */

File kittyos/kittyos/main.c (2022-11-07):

/*
 * kittyos.c
 *
 * Created: 9/2/2018 10:16:59 PM
 * Author : mark
 */ 

#include "kittyos.h"
#include "comm.h"
#include "vga.h"
#include "keyps2.h"
#include "spi.h"
#include "sdcard.h"
#include "llfs.h"


//way to output messages to console

char dmesg_buf[CONFIG_DMESG_SIZE];

chardevice_t* dev_dmesg = NULL;

//simple i/o

void prints(chardevice_t* dev, char* s){
	
	if (!dev)
		return;
		
	if (dev->dev.flags & DEV_FLAG_UNINIT)
		return;
	
	if (!s)	
		printf("Null");
		
	while(*s) 
		dev->write1(dev, *(s++));
}



uint16_t reads( chardevice_t* dev, char* str, uint16_t buffersize, unsigned char echo) {
	uint8_t c=0;
	uint16_t cnt = 1; //1 instead if 0 to reserve space for terminator
	
	while ((cnt < buffersize))
	{
		c = dev->read1(dev);
		
		DMESGF("{recv %d}", c);
		
		if(echo) {
			dev->write1(dev,c); //echo it	
		}
		
		if (c=='\n')
			break; //done
			
		if (c=='\r')
			break; //done
		
		*(str++) = c;
		cnt++;
	}
	
	*str = 0; //null terminate
	return cnt;
}

//The main system mux, which lets the user select all other devices
//also tests the mux enumerate & select subdevice concept, which will be used later to build directories on disk
char* devlistnames[]={"ser0", "spi0", "ps2", "key", "scr",  NULL};	
device_t* devlist []={&dev_ser0.dev, &dev_spi0.chardev.dev, &dev_keyraw.dev, &dev_keychar.dev, &dev_scr.dev };
uchar devtypes[] = { DEVICE_CHAR, DEVICE_CHAR, DEVICE_CHAR, DEVICE_CHAR, DEVICE_CHAR};

device_t* main_select(muxdevice_t* mux, uint16_t subdevice){
	return devlist[subdevice];	
}

uchar main_next(muxdevice_t* mux, deviceinfo_t* info){
	info->selector++;
	if (devlistnames[info->selector] == NULL)
		return 0;  //no more devices
	
	strncpy(&info->name, devlistnames[info->selector], sizeof(info->name));
	info->devtype = devtypes[info->selector];
	return 1; //got a device
}

uchar main_first(muxdevice_t* mux, deviceinfo_t* info){
	info->selector=0xffff;
	return main_next(mux,info);
	
}

uchar (*next)(struct muxdevice_s* mux, deviceinfo_t* info);

muxdevice_t mainmux = { {NULL,0}, main_select, main_first, main_next};
	
	
//findDevice helper function
//takes a name and find it in the main mux


device_t * findDevice(char* name){
	
	muxdevice_t* m = &mainmux;
	//deviceinfo_t info;
	deviceinfo_t di;
	
	if ( m->first(m, &di) ){
		
		do {
			if (!strcmp(di.name, name)) {
				return m->select(m, di.selector);
			}
			
		} while (m->next(m, &di));
	
	}
	
	return NULL;
}






extern void instr0();
extern void instrlast();


unsigned char vstack[100];
extern char program[];




unsigned int syscall(unsigned int arg0, unsigned char callnum, unsigned int arg1, unsigned int arg2);
int main(void)
{	
//	static char buf[50];
	

	
   	/* Disable JTAG port to get full access on PORTC*/
   	MCUCR |= _BV(JTD);
   	MCUCR |= _BV(JTD);
   	DDRA=0;    //all input
   	PORTA=0xff;   //pullup

	//syscall(0x2524, 0xcc, 0x2120, 0x1918);
   //initialize serial port
  
   DMESG("KS\r\n");  //testing that unitialized console does nothing bad
    
   if (SUCCESS == dev_ser0.dev.ioctl(&dev_ser0.dev, IOCTL_BAUD, CONFIG_SER0_BAUD)) {
	   // if we initalized serial port, that becomes the output console
	   dev_dmesg = &dev_ser0;
	   DMESGF("DMESG=SER0 at %d\r\n", CONFIG_SER0_BAUD);
   }
     
	DMESG("Kernel\r\n");
	
	DMESGF("instr0:%x %x\r\n", (unsigned int) instr0, (unsigned int) instrlast);	

	xram_init();  
	vga_init();
	sei();
		
	//switch output to screen, using the device syscall
	DMESG("Attempt to find 'scr'\r\n");
	dev_dmesg = findDevice("scr");

	
	clearscreen(GREEN);
	dev_keyraw.dev.ioctl(&dev_keyraw.dev, IOCTL_ENABLE, 1);

	DMESG("DMESG=scr\r\n");
	DMESG("VER 0.21 "  __DATE__ " " __TIME__  " \r\n");
	
	dev_dmesg = &dev_ser0;
	unsigned long cap;
	DMESG("card init\n");
	sdcard_init(&cap); //init sdcard driver, get capacity
	DMESG(" init disk\n");
	//initDisk(cap); //format the disk (write some stuff to block 0)
	mount(); //see if it mounts	
	DMESG("mount\n");
	
	blockInfo pos;
	blockRoot(&pos);
	blockSetData(&pos, "ROOTBLOCK", 10);
	
	
	blockAddFirstChild(&pos, "Hello SDCard", 13);
	blockInsert(&pos, "Another block", 14);
	blockInfo posChild = pos;	//copy the position object!
	blockAddFirstChild(&posChild, "Child", 6);
	blockAppendData(&pos, "-appending-block", 17 );  //editing the same 'file' but in two places at once!
	blockAppendData(&posChild, "-appending-child", 17 );
	
	char str[20];
	blockRoot(&pos);
	blockReadData(&pos, str, 20);
	DMESGF("%20s\r\n", str);
	blockFirstChild(&pos);
	blockReadData(&pos, str, 20);
	DMESGF("%20s\r\n", str);
	
	unmount();
	mminit();
	mmdump();
	
	xalloc_init(32768,65535);
	//xdump();
	
	dev_dmesg = &dev_scr;
	DMESGF("SDCARD size %ld\r\n", cap);
	

	dev_dmesg = &dev_ser0;
	/*
	void* a = xalloc(10);
	void* b = xalloc(20);
	void* c = xalloc(30);
	xfree(b);
	xdump();
	xfree(a);
	xfree(c);
	xdump();
	xalloc(55);
	xdump();
	*/
	/*
	mmalloc(200);
	void* v1  = mmalloc_handle(200, 0x55);
	void* v2 = mmalloc_handle(230, 0x1033);
	void* v3 = mmalloc_handle(512, 0x5556);
	//mmdump();
	DMESGF("H %x %x %x\r\n", mmgethandle(v1), mmgethandle(v2) ,  mmgethandle(v3)  );
	
	DMESGF("P %p %p %p\r\n", v1,v2,v3);
	
	DMESGF("P %p %p %p\r\n", mmfindhandle(0x55) ,mmfindhandle(0x1033),mmfindhandle(0x5556));
	

	
    xalloc_init(32768,65535);
	//xdump();
	
	//xalloc(100);
	char* s = "This is a string";
	
	char * hp;
	char * hp2;
	
	u16 h = halloc(strlen(s)+1);
	hp = hgrab(h);
	hp2 = hgrab(h); //get again
	DMESGF("hp %p  hp2 %p\r\n", hp, hp2);
	
	strcpy(hp, s);  //copy it
	
	hrelease(hp);
	hrelease(hp2);
	
	char* other = mmalloc(10); //take up some memory (should overhap old hp)
	DMESGF("other %p\r\n", other);
			
	hp = hgrab(h);
	DMESGF("hp %x %s\r\n",hp,hp);
	
	
	#if 1
	{
		deviceinfo_t di;
		if ( mainmux.first(&mainmux, &di) ){
			
			do {
				DMESGF("DEVICE %s=T%x S%x,\n", di.name, di.devtype, di.selector);
			} while (mainmux.next(&mainmux, &di));
		}
				
		
	}
	
	DMESG("--\n");
	#endif
	   	environment_t env;
	   	env.in = &dev_keychar;
	   	env.out = &dev_scr;
	   	//env.cmdline= " testing";
	   	//env.in = &dev_ser0;
	   	//env.out = &dev_ser0;
*/

		//interpreter never returns
	DMESGF("Start 16:$%x\n", (unsigned int) program);
	interpreter(program, vstack + sizeof(vstack), NULL);
	
	//dev_spi0.chardev.dev.ioctl(&dev_spi0.chardev.dev, IOCTL_LOCK, SPI_MASTER | SPI_CLK_8 );
	
	//{
		//unsigned long cap;
		//sdcard_init(&cap);
		//DMESGF("SD:%ld\n", cap);
	//}
	
	
	
	//dev_spi0.chardev.write1(NULL, 'A');
	//while(1);
	
	 

   while(1){
	   
	   vscroll++;
	   hscroll-=2;
	   vga_delay(20);
	   
   }
   
  
}

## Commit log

2014-08-19 Initial checkin of code.
    [audio-keyboard.sch, fullcomputer.sch, memory.sch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]
2016-11-02 update schematics. move cat-os to cat-1 to get ready for update
    [fullcomputer.sch, memory.sch]
2016-11-02 kicad project
    [av.sch, cat644.kicad_pcb, cat644.sch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]
2016-11-07 updated pcb
    [av.sch, cat644.dsn, cat644.kicad_pcb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]
2016-11-10 updated pcb
    changed vias to 0.05/0.027 dia/drill
    track size increased to 0.015
    filter caps added to regulator outputs
    [av.sch, cat644.dsn, cat644.kicad_pcb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]
2016-11-24 Switch hsync and vsync lines for an upcoming optimization
2016-11-28 updated pcb with header on unused pins and extra pad for 117 regulator
    [av.sch, cat644.kicad_pcb, cat644.sch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]
2018-09-04 XRAM working on both hardware and simavr. needed to modify simavr memcpyi2x and memcpyx2i copied between internal and external sram. memcpy*2* takes 16 bit addresses. User still needs to select which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
    [main.c, xram.h]
2018-09-06 adding in vga driver. also trying to rewrite a basic vga driver in assembly instead of C to get better control of timing.
2018-09-07 vga fullscreen working w/ horizontal and vertical scrolling, and limited vertical window
    todo:
    enable oddonly 'fast mode'
    enable limited horizontal window for horz scrolling
    need to reimplement ps2 polling: the original cat1 demo program used polled the ps2 inputs once per scanline to avoid interrupt conflicts
    [main.c, vga.c, vga.h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]
2018-09-07 added 'skippy' video mode which draws every other video line, and gives about 50% of the cpu back to the main program
    TODO: still need to add in ps2keyboard polling.
    idea for polling: the original cat1 demo driver sampled at around hsync (the same time each line), and then if the sample showed a change, at the END of the scanline, it handled the key. I did this in the blanking interval instead of returning to the main application. I may have to do that here. If the change happened on a blank or skippy line, there's no problem.
    For now, if it shows a change, lets just aboirt the current line. it'll disrupt the display, but whatever.
    Also might be able to just 'notch' the display off t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
    [main.c, vga.c]
2018-09-12 fix 525 lines scanlines instead of 512
    [main.c]
2018-09-13 experimenting with replacing some of the pixel output code with NOPs if I can do the same thing but with some of the instructions nops, then the nops can be replaced with something useful
    [xram.h]
2018-09-14 saving some code here that messes with Timer 0, which might be used as a hardware bit flipper for some pixels
    [vga.c]
2018-09-18 reading keyboard OK, but it glitches screen (counter bug)
    [main.c, vga.c, vga.h]
2018-09-19 fix ram bank bug (probably) fix keybuffer increment bug add reading keyboard is raw chardevice (get scancodes)
    [main.c, vga.c]
2018-09-20 Capture keyboard port state and change flag at front of the line routine. Active scanlines are shortened to handle the keyboard. Screen is indisturbed when typing. TODO: When there is no keyboard act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
    Test starts in vidfull (The HARD case, because there's no blank lines to abuse)
    Test ends wth
    [vga.c]
2018-09-24 Bring in old spi driver from abandoned catos
2018-09-26 add in cat-os sdcard driver, and modify for kittyos. Only so far tested the sdcard init function, which returns the correct size of the sdcard (so I guess it works?)
    fixed some ps2 warnings
    [main.c, sdcard.c]
2018-09-27 runs a small program inside bytecode interpreter (adds two numbers, outputs via dummy syscall) also checking in the cross assembler
    this interpreter and assembler was originally prototyped a long time ago
    but now its finally in
2019-03-17 Fix newline bug rename vga-bad to vga-speg add build date/time
    [main.c, vga.c]
2022-11-07 Committing changes for the retrochallenge 2022/10 This includes 1 bugfix made after the competition ended: SDCard CS line handling... sometimes caused things to fail
    [main.c]
